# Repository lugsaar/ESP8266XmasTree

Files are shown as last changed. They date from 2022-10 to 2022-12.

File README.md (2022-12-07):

# ESP8266 Xmas Tree

 [][cc-by-nc-sa]

ESP8266 based PCB Xmas tree with WS2812B LEDs as Christmas lights. The Christmas tree can be easily controlled with systems like Tasmota or ESPHome. It is very simple to integrate the Christmas tree into any SmartHome environment. To control the LEDs you can also use the standard development tools for ESP MCUs. To be more flexible, the connection of the MCU and sensor is mounted via female pin header. Components like capacitors are a bit bigger in the footprint to build the Xmas tree without special tools. Only a standard electronic soldering iron and solder is needed. With soldering paste it is a little easier. 

## Building the first batch

<p align="center">
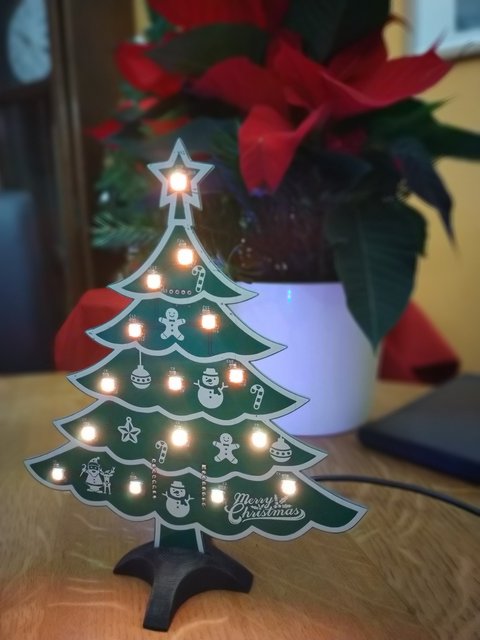
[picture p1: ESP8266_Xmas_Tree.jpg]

</p>

<br>

<div align="center">
  <video  src="https://user-images.githubusercontent.com/16343380/206121300-22d0379d-260c-4d33-9b2b-982ff7118add.mp4" width"480"/>
</div>

## Layout

<p align="center">
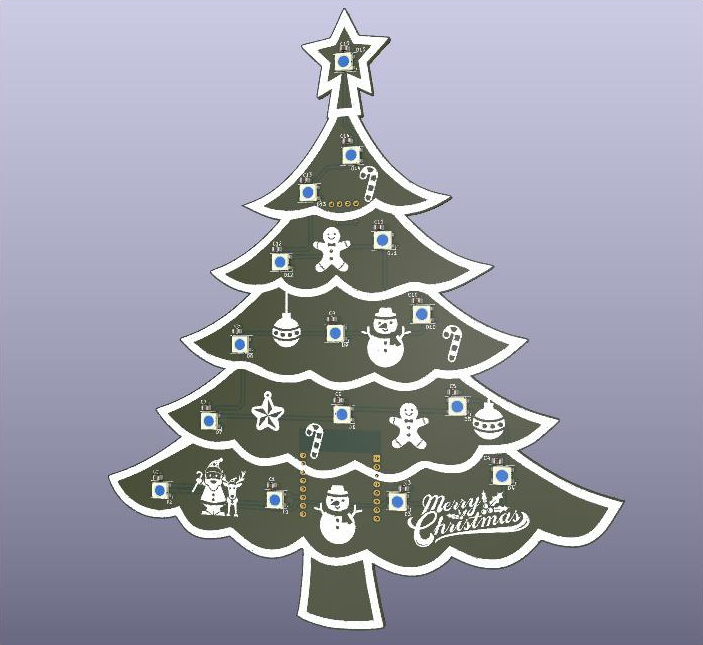
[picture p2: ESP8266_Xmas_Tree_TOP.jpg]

</p>

<p align="center">
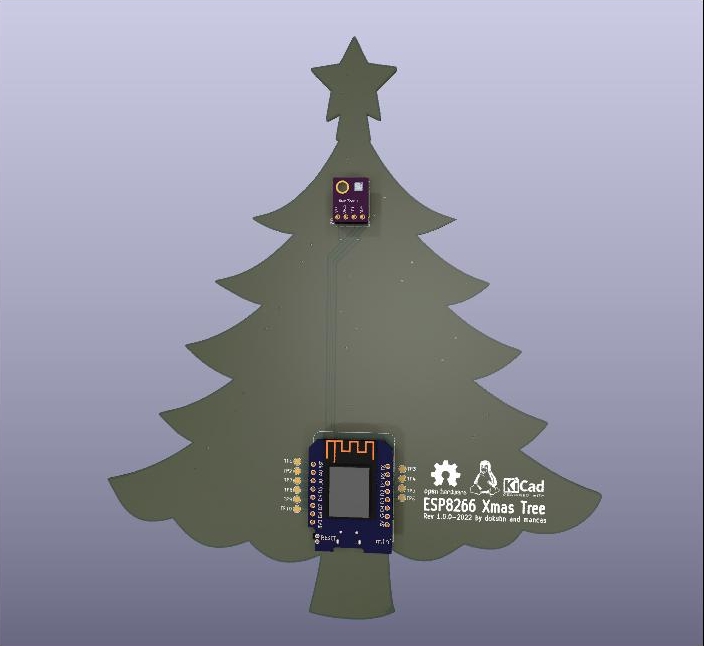
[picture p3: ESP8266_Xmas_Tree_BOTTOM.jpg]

</p>

## ToDos

- Fixing EdgeCuts problem to be able to build step file

## License 

This work is licensed under a
[Creative Commons Attribution-NonCommercial-ShareAlike 4.0 International License][cc-by-nc-sa].

[][cc-by-nc-sa]

[cc-by-nc-sa]: http://creativecommons.org/licenses/by-nc-sa/4.0/
[cc-by-nc-sa-image]: https://licensebuttons.net/l/by-nc-sa/4.0/88x31.png
[cc-by-nc-sa-shield]: https://img.shields.io/badge/License-CC%20BY--NC--SA%204.0-lightgrey.svg

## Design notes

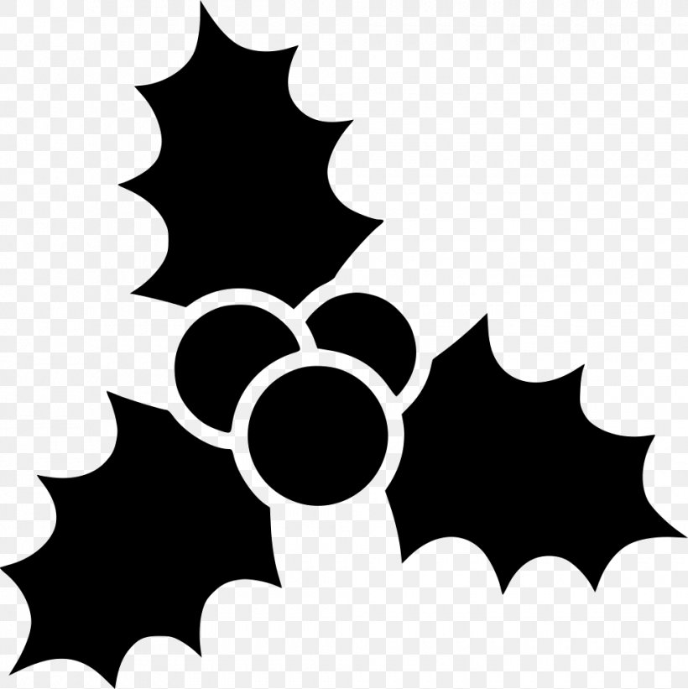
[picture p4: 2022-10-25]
Graphics/mistletoe.jpeg

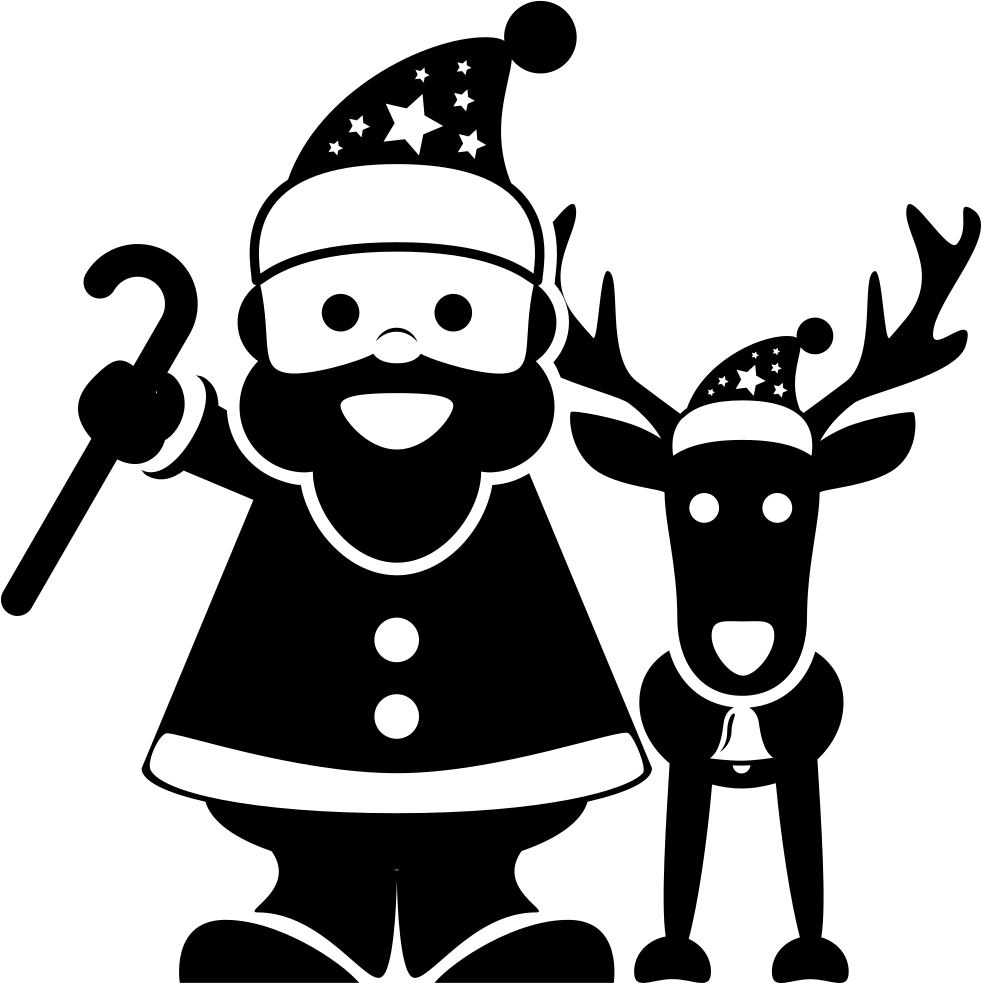
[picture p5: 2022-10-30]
Graphics/Xmas_claus.png

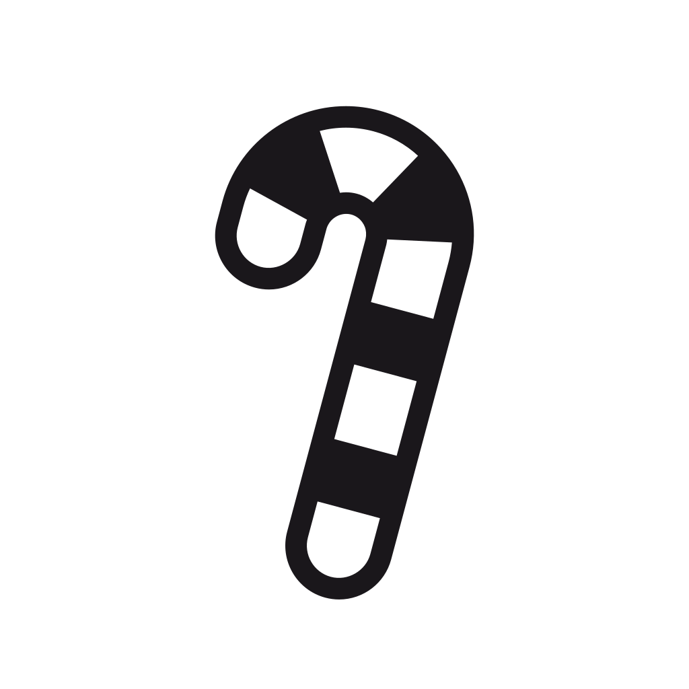
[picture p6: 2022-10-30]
Graphics/Xmas_canes.png

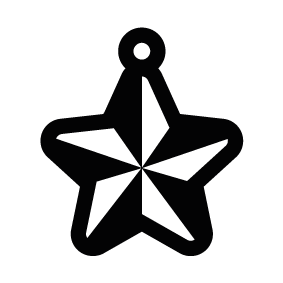
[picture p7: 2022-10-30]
Graphics/Xmas_star.png

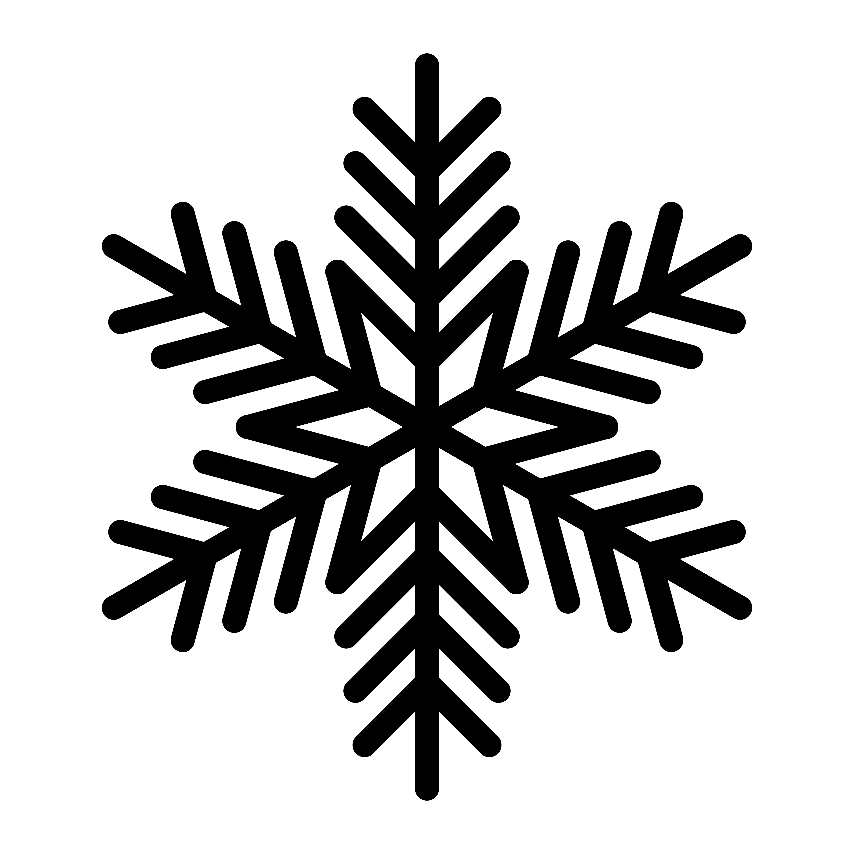
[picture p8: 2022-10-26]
Graphics/snowflake.jpeg

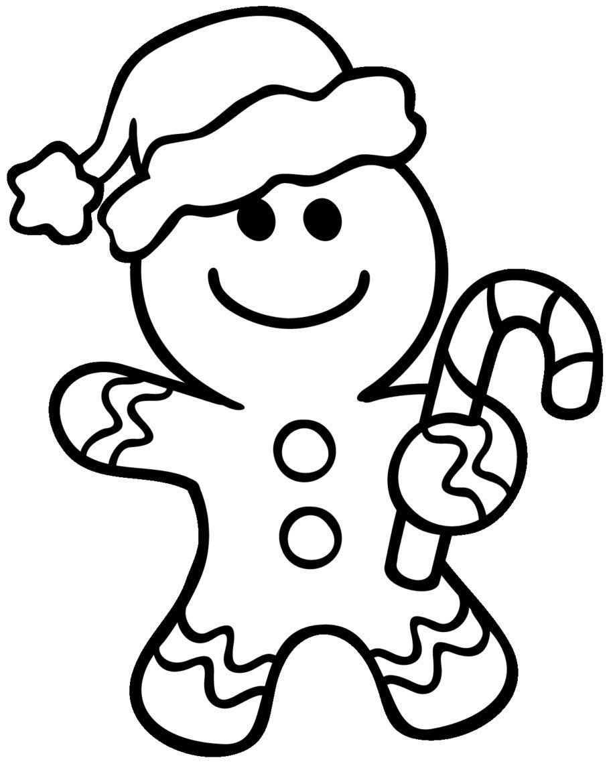
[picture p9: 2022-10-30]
Graphics/Xmas_gingerbreadmen_canes.jpg

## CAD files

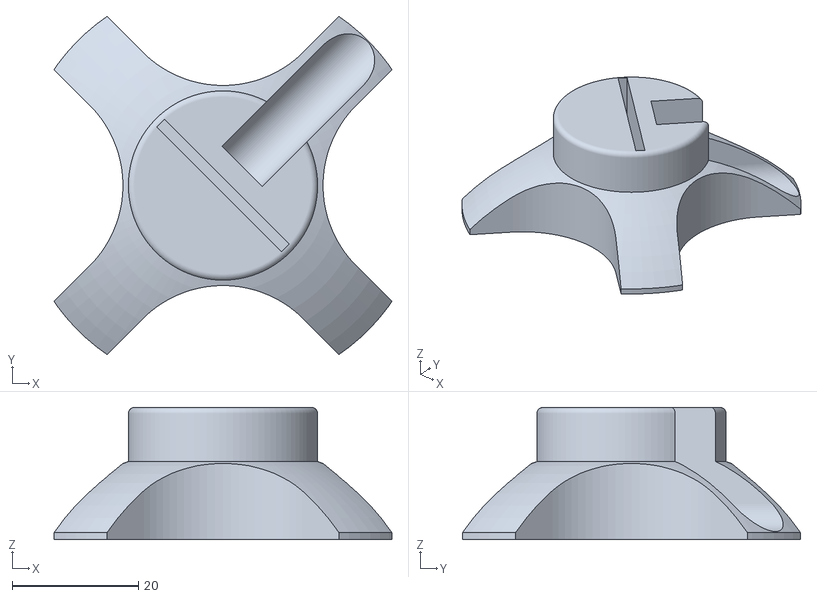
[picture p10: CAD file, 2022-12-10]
XmasTreeStand/XmastreeStand_extended.stl
53.6 x 53.6 x 21.0

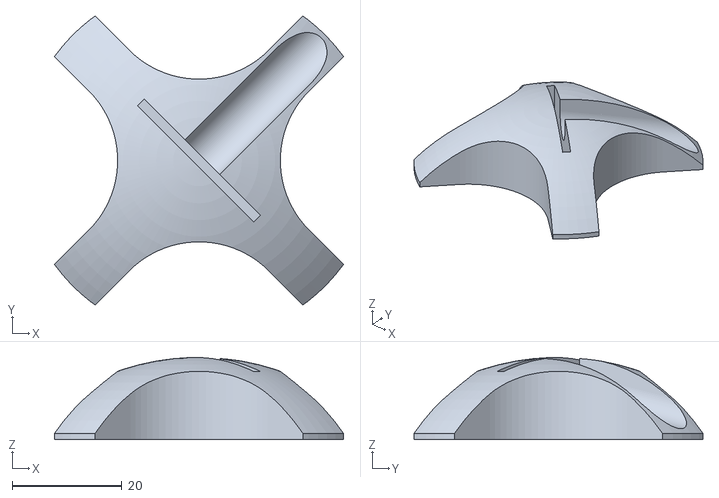
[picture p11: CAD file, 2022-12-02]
XmasTreeStand/XmastreeStand_V4.stl
52.8 x 52.7 x 15.0

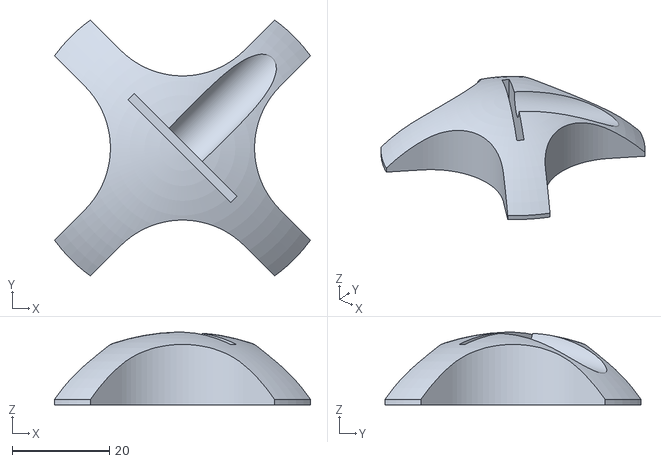
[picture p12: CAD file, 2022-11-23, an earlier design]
XmasTreeStand/XmastreeStand_V3.stl
52.8 x 52.7 x 15.0

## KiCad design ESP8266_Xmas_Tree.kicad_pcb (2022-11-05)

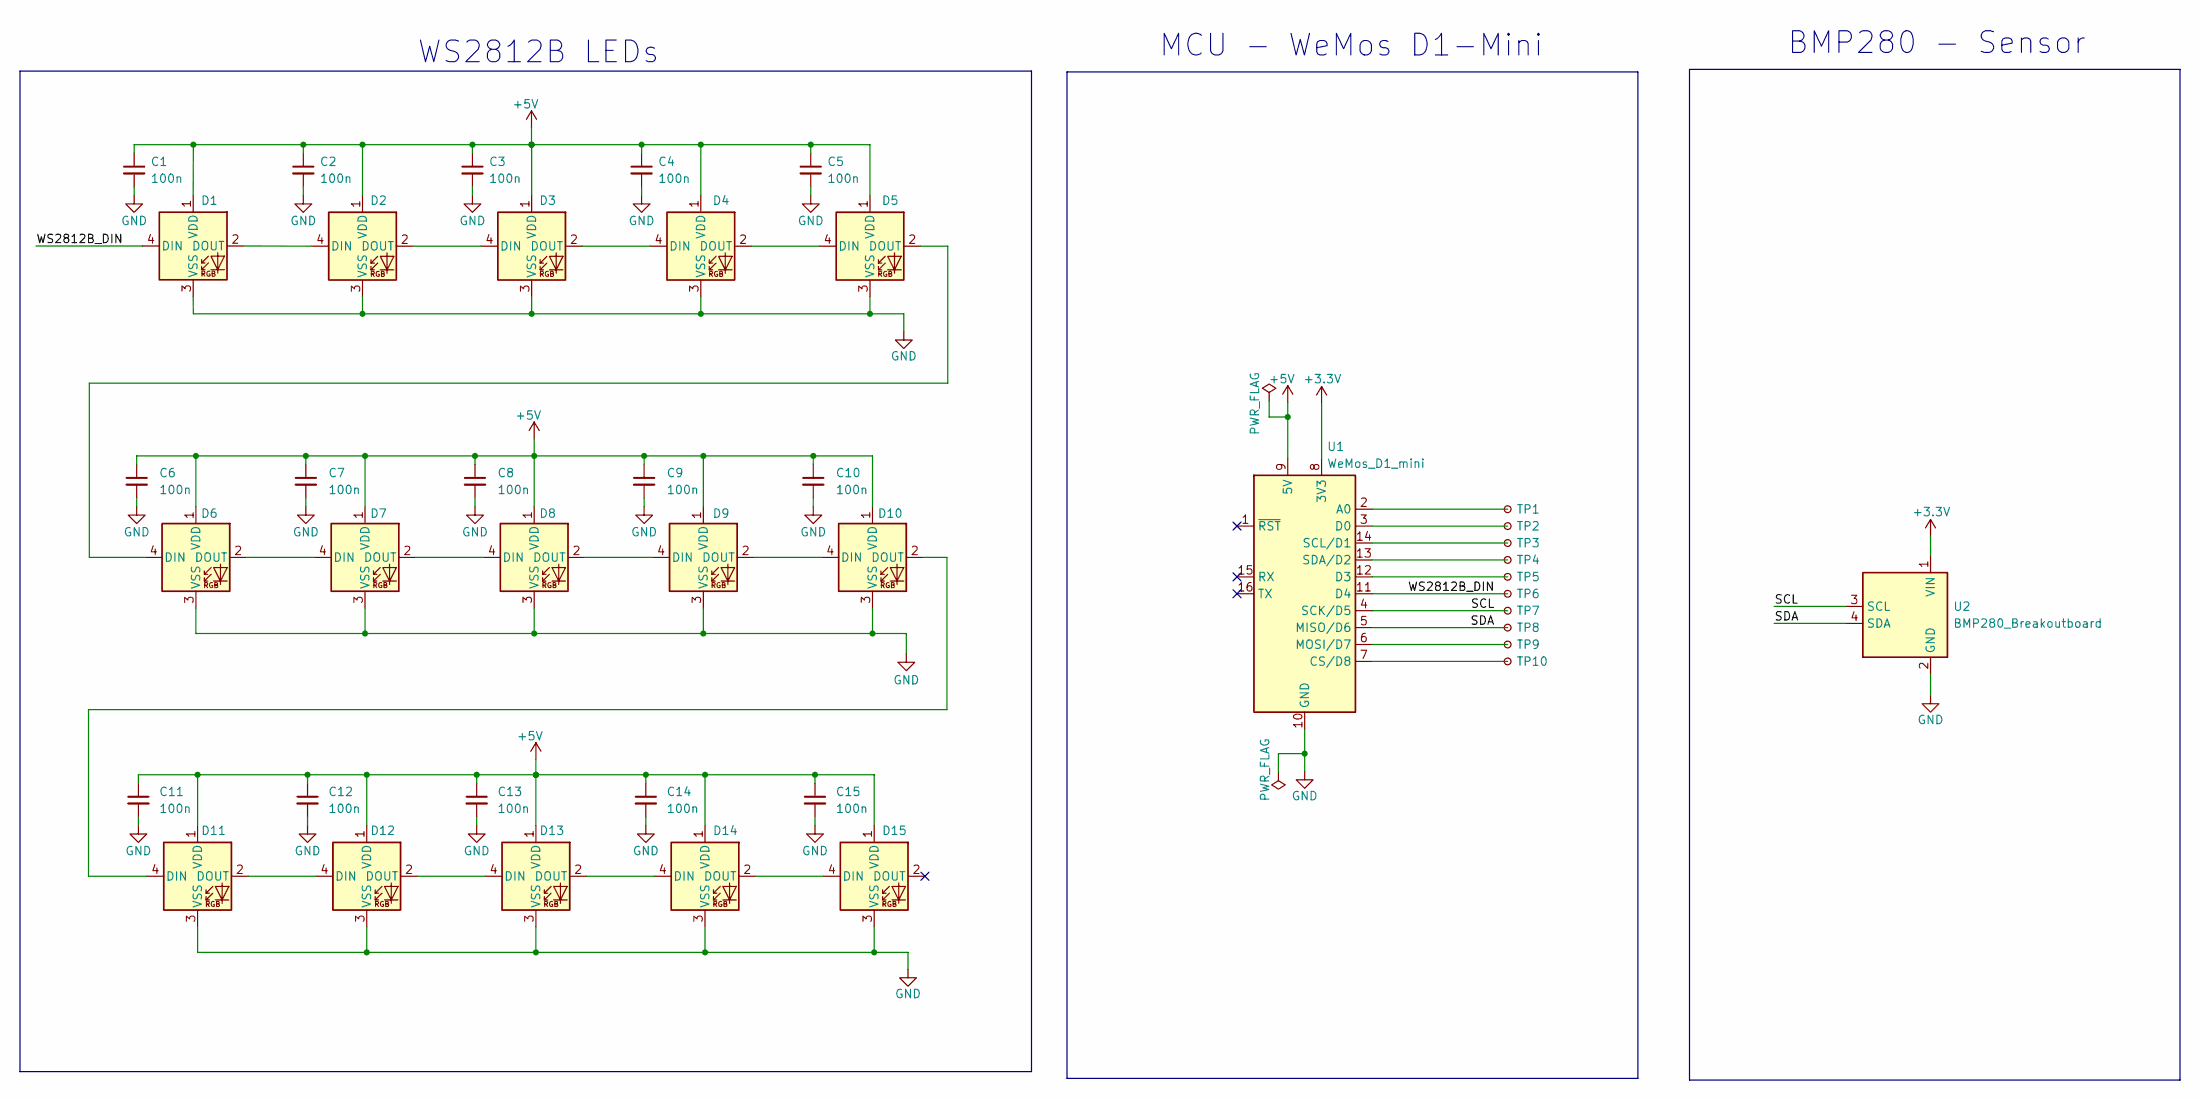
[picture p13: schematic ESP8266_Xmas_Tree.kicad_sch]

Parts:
C1, C2, C3, C4, C5, C6, C7, C8, C9, C10, C11, C12, C13, C14, C15: 100n; C_0805_2012Metric_Pad1.18x1.45mm_HandSolder
D1, D2, D3, D4, D5, D6, D7, D8, D9, D10, D11, D12, D13, D14, D15: WS2812B; LED_WS2812B_PLCC4_5.0x5.0mm_P3.2mm
TP1, TP2, TP3, TP4, TP5, TP6, TP7, TP8, TP9, TP10: TestPoint_Small; TestPoint_Pad_D2.0mm
U1: WeMos_D1_mini; WEMOS_D1_mini_light
U2: BMP280_Breakoutboard

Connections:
+3.3V: U1.8 (3V3), U2.1 (VIN)
+5V: C1.1, C2.1, C3.1, C4.1, C5.1, C6.1, C7.1, C8.1, C9.1, C10.1, C11.1, C12.1, C13.1, C14.1, C15.1, D1.1 (VDD), D2.1 (VDD), D3.1 (VDD), D4.1 (VDD), D5.1 (VDD), D6.1 (VDD), D7.1 (VDD), D8.1 (VDD), D9.1 (VDD), D10.1 (VDD), D11.1 (VDD), D12.1 (VDD), D13.1 (VDD), D14.1 (VDD), D15.1 (VDD), U1.9 (5V)
/SCL: TP7.1, U1.4 (SCK/D5), U2.3 (SCL)
/SDA: TP8.1, U1.5 (MISO/D6), U2.4 (SDA)
/WS2812B_DIN: D1.4 (DIN), TP6.1, U1.11 (D4)
GND: C1.2, C2.2, C3.2, C4.2, C5.2, C6.2, C7.2, C8.2, C9.2, C10.2, C11.2, C12.2, C13.2, C14.2, C15.2, D1.3 (VSS), D2.3 (VSS), D3.3 (VSS), D4.3 (VSS), D5.3 (VSS), D6.3 (VSS), D7.3 (VSS), D8.3 (VSS), D9.3 (VSS), D10.3 (VSS), D11.3 (VSS), D12.3 (VSS), D13.3 (VSS), D14.3 (VSS), D15.3 (VSS), U1.10 (GND), U2.2 (GND)
unnamed: D1.2 (DOUT), D2.4 (DIN)
unnamed: D2.2 (DOUT), D3.4 (DIN)
unnamed: D3.2 (DOUT), D4.4 (DIN)
unnamed: D4.2 (DOUT), D5.4 (DIN)
unnamed: D5.2 (DOUT), D6.4 (DIN)
unnamed: D6.2 (DOUT), D7.4 (DIN)
unnamed: D7.2 (DOUT), D8.4 (DIN)
unnamed: D8.2 (DOUT), D9.4 (DIN)
unnamed: D10.2 (DOUT), D11.4 (DIN)
unnamed: D9.2 (DOUT), D10.4 (DIN)
unnamed: D11.2 (DOUT), D12.4 (DIN)
unnamed: D12.2 (DOUT), D13.4 (DIN)
unnamed: D13.2 (DOUT), D14.4 (DIN)
unnamed: D14.2 (DOUT), D15.4 (DIN)
unnamed: TP1.1, U1.2 (A0)
unnamed: TP2.1, U1.3 (D0)
unnamed: TP3.1, U1.14 (SCL/D1)
unnamed: TP4.1, U1.13 (SDA/D2)
unnamed: TP5.1, U1.12 (D3)
unnamed: TP9.1, U1.6 (MOSI/D7)
unnamed: TP10.1, U1.7 (CS/D8)

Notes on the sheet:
BMP280 - Sensor
WS2812B LEDs
MCU - WeMos D1-Mini

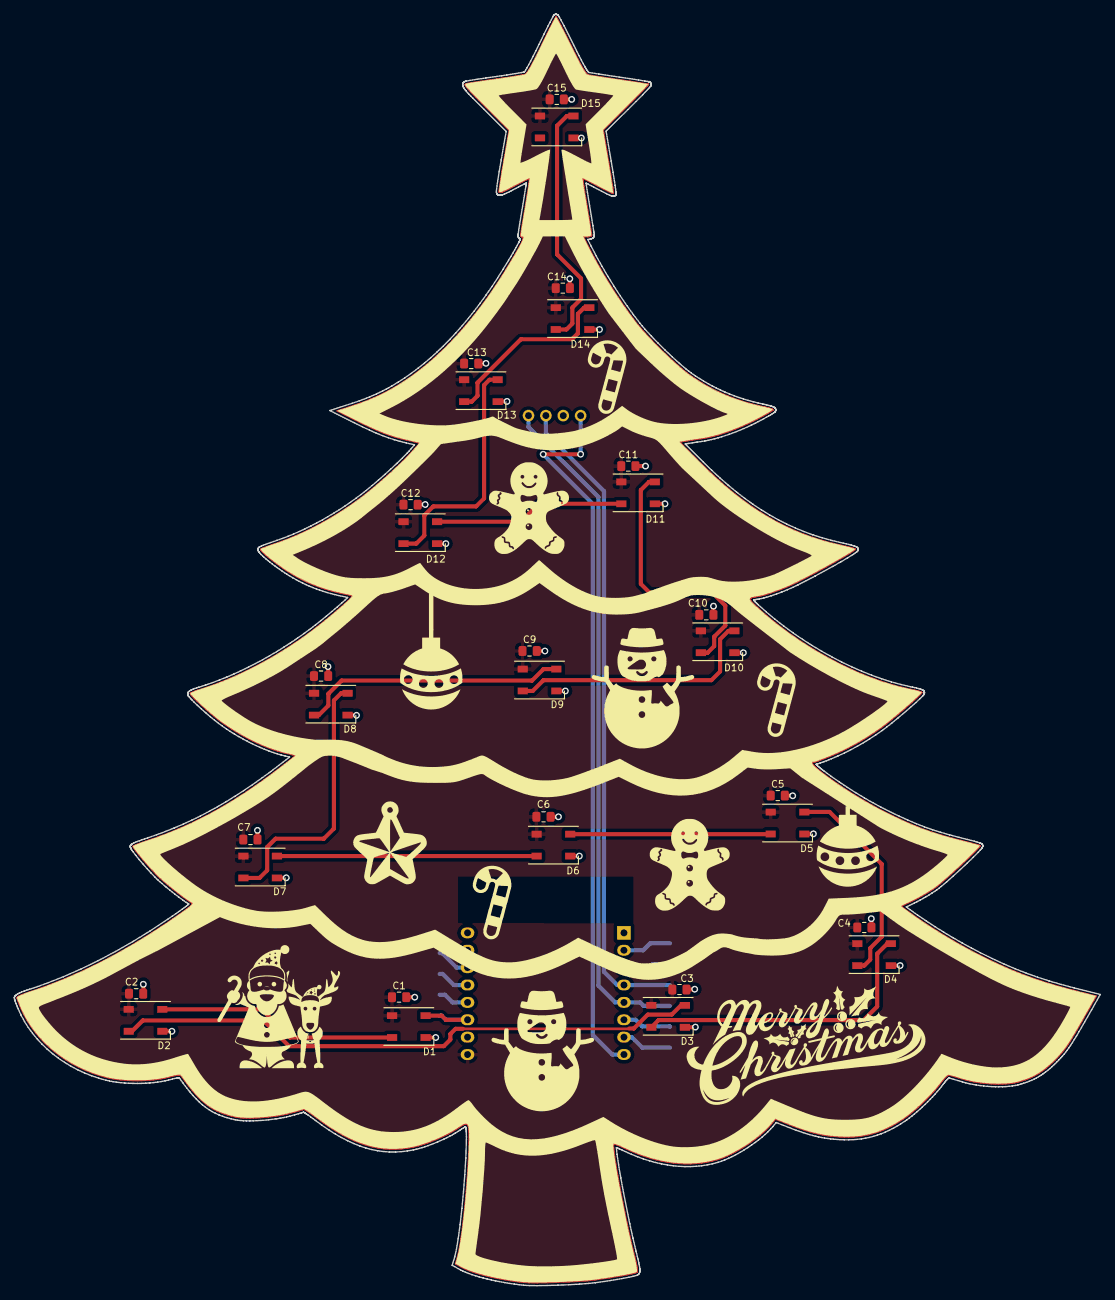
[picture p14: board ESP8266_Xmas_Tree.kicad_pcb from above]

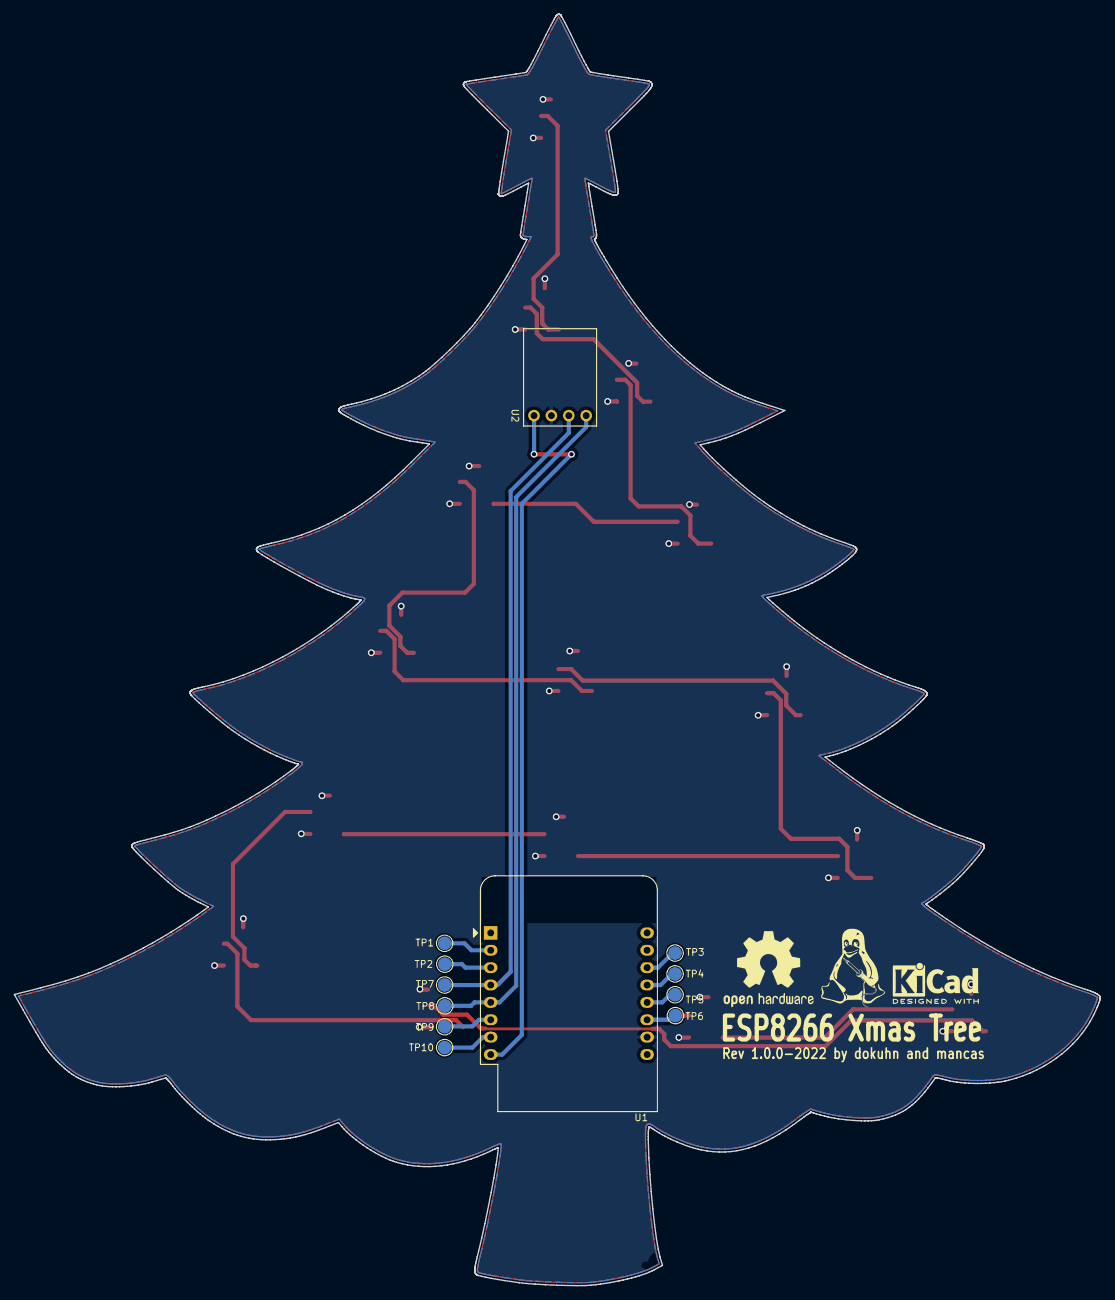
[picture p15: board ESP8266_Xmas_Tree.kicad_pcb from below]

Board: 2 copper layers, 158.7 x 185.8 mm, 42 parts (12 on the bottom side), 27 nets.

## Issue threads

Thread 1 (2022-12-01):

Last state not stored

mase76, 2022-12-01:
Hi,
after a power on reset, the tree should continue with the last state.

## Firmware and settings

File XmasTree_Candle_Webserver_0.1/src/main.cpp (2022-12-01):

// ----------------------------------------
// first try, started by mancas@lug-saar.de
// 2022-11-20
// ----------------------------------------

#include <SoftwareSerial.h>
#include <ESP8266WiFi.h>
#include <ESPAsyncWebServer.h>


#include "custom_params.hpp"
#include "pacifica.hpp"
#include "pride.hpp"

CRGB leds[NUM_LEDS];



// wifi and webserver setup parameters
const char* PARAM_INPUT_1 = "input1";
String globalinputMessage = "empty";  // Website input String

// Set these to your desired credentials.
const char *ssid = "Xmastree2";
//const char *password = "12345678";

// Create AsyncWebServer object on port 80
AsyncWebServer server(80);

// HTML web page to handle input
const char index_html[] PROGMEM = R"rawliteral(
  <!DOCTYPE HTML><html><head>
  <title>my XmasTree</title>
  <meta name="viewport" content="width=device-width, initial-scale=1">
  </head><body>
  <H3> Welcome to your Xmas tree</H3><br>
  Movie 1 - pacifica<br>
  Movie 2 - pride<br>
  Movie 3 - calme change<br><br>
  <form action="/get">
  chose your LED Movie: <br>
  <input type="text" name="input1"><br>
  <input type="submit" value="Submit">
  </form><br>
  </body></html>)rawliteral";

void notFound(AsyncWebServerRequest *request) {
  request->send(404, "text/plain", "Not found");
}


// system setup
void setup() {
  // pinMode(LED_BUILTIN, OUTPUT);
  //pinMode(ledPin, OUTPUT);
  //digitalWrite(ledPin, LOW);

  delay( 3000); // 3 second delay for boot recovery, and a moment of silence
  FastLED.addLeds<LED_TYPE,DATA_PIN,COLOR_ORDER>(leds, NUM_LEDS)
        .setCorrection( TypicalLEDStrip );
  FastLED.setMaxPowerInVoltsAndMilliamps( 5, MAX_POWER_MILLIAMPS);
  
  
  Serial.begin(115200);
  Serial.println();
  Serial.println("Configuring access point...");



  // WiFi.softAP(ssid, password);
  WiFi.softAP(ssid); //open AP
  IPAddress myIP = WiFi.softAPIP();
  Serial.print("AP IP address: "); 
  Serial.println(myIP);

  
  // start the Webserver
  Serial.println("starting webserver");


  server.on("/", HTTP_GET, [](AsyncWebServerRequest *request){
    request->send_P(200, "text/html", index_html);
  });

  


  // Send a GET request to <ESP_IP>/get?input1=<inputMessage>
  server.on("/get", HTTP_GET, [] (AsyncWebServerRequest *request) {
  String inputMessage;
  String inputParam;
   
  // GET input1 value on <ESP_IP>/get?input1=<inputMessage>
    
    if (request->hasParam(PARAM_INPUT_1)) {
      inputMessage = request->getParam(PARAM_INPUT_1)->value();
      inputParam = PARAM_INPUT_1;
      globalinputMessage = inputMessage; //gebe weiter an globale Variable
    }

  
    else {
      inputMessage = "No message sent";
      inputParam = "none";
      globalinputMessage="empty";
    }
    
    //Serial.println(inputMessage);
    request->send(200, "text/html", "<br><a href=\"/\">You will get it, click to return </a>"); 
    
    }


  );

  server.onNotFound(notFound);
  server.begin();
  globalinputMessage = "2";

}

// run Xmas tree

  void loop()
  {

    if (globalinputMessage == "1")
    {
      EVERY_N_MILLISECONDS(20)
      {
        pacifica_loop();
        FastLED.setBrightness(BRIGHTNESS);
        FastLED.show();
      }
    }
    else if (globalinputMessage == "2")
    {
      pride();
      FastLED.setBrightness(BRIGHTNESS);
      FastLED.show();
    }

}

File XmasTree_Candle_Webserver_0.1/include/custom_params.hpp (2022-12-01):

#ifndef CUSTOM_PARAMS_HPP
#define CUSTOM_PARAMS_HPP

#include <FastLED.h>

FASTLED_USING_NAMESPACE

// LED setup parameters
# define FASTLED_ALLOW_INTERRUPTS 0


#define DATA_PIN            2
#define NUM_LEDS            15
#define MAX_POWER_MILLIAMPS 500
#define LED_TYPE            WS2812B
#define COLOR_ORDER         GRB

#define BRIGHTNESS          48

#define LED_BUILTIN 2   // Set the GPIO pin where you connected your test LED or comment this line out if your dev board has a built-in LED

extern CRGB leds[];


#endif

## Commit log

2022-10-25 first init
    [ESP8266_Xmas_Tree.kicad_pcb, ESP8266_Xmas_Tree.kicad_sch, Xmas_Tree.dxf]
2022-10-26 adding some nice graphics like gingerbreak man and snowflakes to silkscreen
    [ESP8266_Xmas_Tree.kicad_pcb]
2022-10-26 adding d1 mini step model to pcb
    [ESP8266_Xmas_Tree.kicad_pcb, ESP8266_Xmas_Tree.kicad_sch]
2022-10-27 adding caps for WS2812B LEDs
    [ESP8266_Xmas_Tree.kicad_pcb, ESP8266_Xmas_Tree.kicad_sch]
2022-10-28 adding 3V3 and GND to MCU
    [ESP8266_Xmas_Tree.kicad_pcb, ESP8266_Xmas_Tree.kicad_sch]
2022-10-30 adding Edge Cuts, Silkscreen an filled zones from SVG files
    [ESP8266_Xmas_Tree.kicad_pcb, Xmas_Tree.dxf]
2022-10-30 adding Xmas balls, canes and santa claus to PCB in silkscreen
    [ESP8266_Xmas_Tree.kicad_pcb]
2022-11-02 Fix the naming error of the capacitors and change the supply voltage from 3V3 to 5V of the LEDs.
    [ESP8266_Xmas_Tree.kicad_pcb, ESP8266_Xmas_Tree.kicad_sch]
2022-11-03 adding BMP280 Breakoutboard Lib and footprint to PCB
    [ESP8266_Xmas_Tree.kicad_pcb, ESP8266_Xmas_Tree.kicad_sch]
2022-11-04 first routing
    [ESP8266_Xmas_Tree.kicad_pcb]
2022-11-05 adding README file
    [ESP8266_Xmas_Tree.kicad_pcb]
2022-11-06 ignoring Gerber files in repo
2022-11-23 XmasTreeStand added, brightness reduced
    [XmastreeStand_V3.stl]
2022-12-01 Port firmware from Arduino IDE to platformio development environment
2022-12-02 Xmastre stand update
    [XmastreeStand_V4.stl]
2022-12-10 XmastreeStand extended for big usb connectors
    [XmastreeStand_extended.stl]

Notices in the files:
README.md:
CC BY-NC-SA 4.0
